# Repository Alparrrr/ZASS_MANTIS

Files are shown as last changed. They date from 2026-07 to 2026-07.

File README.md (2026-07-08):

# ZASS MANTIS — Battery Display & Logger Unit

STM32-based display and control unit designed for **ZASS Lithium Battery Packs**.

The system reads battery telemetry over **FDCAN / RS485**, visualizes it on a **DWIN HMI** touch screen via UART, and logs every frame received from the pack to an SD card.

<p align="center">
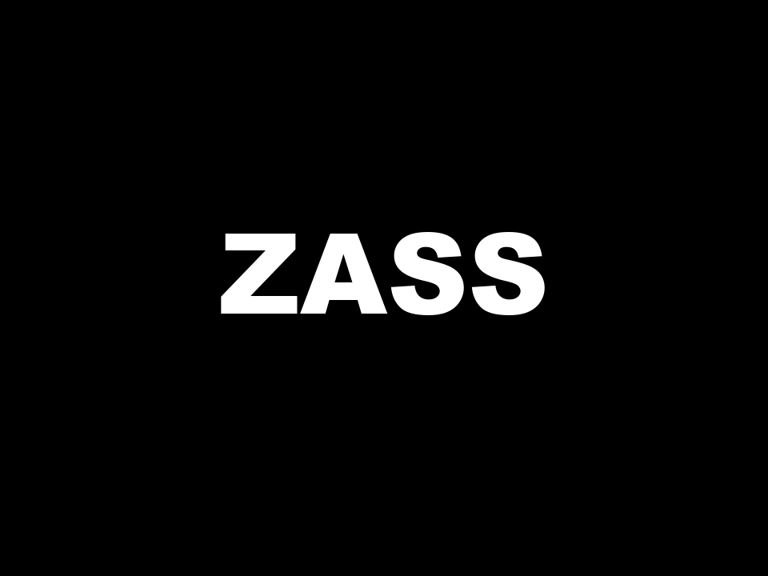
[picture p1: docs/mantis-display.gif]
ZASS MANTIS display — boot screen and live telemetry dashboard
  
  <br/>
  <em>Boot sequence and live telemetry dashboard (DWIN HMI, 320×240)</em>
</p>

## Features

- 📊 Displays cell voltages, total pack voltage, SOC and temperature
- 🔌 **2× FDCAN** and **1× RS485** communication ports
- 🖥️ **UART** driver for the DWIN HMI display
- ⚠️ Detailed fault monitoring (over-voltage, under-voltage, over-temperature, over-current)
- 💾 Full data logging to SD card (FATFS) — every frame coming from the pack is stored

## Communication Flow

```
BMS ──(FDCAN / RS485)──▶ MANTIS ──(UART / FDCAN)──▶ DWIN DISPLAY
        raw battery data        parsed data & screen variables
```

## SD Card Data Logging

Every frame received from the pack is appended to a daily CSV file. Logs are organized into year / month folders on the SD card:

```
/2026/07_2026/09_07_2026_LOG.CSV
```

Example log content:

```csv
2026.07.09 14:32:01,52.61,3287,3290,3288,3286,3291,3289,3287,3285,26,25,-14.6,78
2026.07.09 14:32:02,52.60,3287,3289,3288,3286,3290,3289,3286,3285,26,25,-14.8,78
2026.07.09 14:32:03,52.58,3286,3289,3287,3285,3290,3288,3286,3284,26,25,-15.1,78
2026.07.09 14:32:04,52.59,3287,3290,3288,3286,3290,3289,3287,3285,26,25,-14.9,78
```

| Column | Field | Unit |
|---|---|---|
| 1 | Timestamp (RTC) | `YYYY.MM.DD hh:mm:ss` |
| 2 | Total pack voltage | V |
| 3–10 | Cell voltages 1–8 | mV |
| 11 | MOSFET temperature | °C |
| 12 | Battery temperature | °C |
| 13 | Current (+ charge / − discharge) | A |
| 14 | State of charge | % |

## Repository Structure

| Folder | Contents |
|---|---|
| `01_HARDWARE_ALTIUM/` | Altium Designer project, Gerber outputs, BOM, 3D STEP model |
| `02_Firmware_STM32/` | STM32CubeIDE firmware project (`ZASS_MANTIS_114`) |
| `04_DWIN_DISPLAY/` | DWIN HMI screen project and image assets |

## Hardware

- **MCU:** STM32 (2× FDCAN)
- **Display:** DWIN HMI (UART)
- **Storage:** microSD card (FATFS)

## Status

| Milestone | State |
|---|---|
| Hardware design | ✅ Completed |
| First sample PCB | ✅ Ordered & validated |
| **-30 version design** | ✅ **Completed** |
| **Production batch (50 units)** | 🏭 **Ordered** |

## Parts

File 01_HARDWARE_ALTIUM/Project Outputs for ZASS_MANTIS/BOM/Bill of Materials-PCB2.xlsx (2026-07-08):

Comment | Description | Designator | Footprint | LibRef | Quantity
CR2032 | BATTERY LITHIUM 3V COIN 20MM | BT1 | FP-CR2032-MFG | CMP-05417-000003-1 | 1
3034TR | BATTERY RETAINER COIN 20MM SMD | BT2 | FP-3034TR-MFG | CMP-19636-000007-1 | 1
CC0805KRX7R5BB104 | CAP CER X7R 0805 | C1, C2, C5, C8, C11, C12, C14, C15 | FP-CC0805-EA-MFG | CMP-03422-000810-2 | 8
C0805C104K5RACTU | CAP CER 0.1UF 50V X7R 0805 | C3, C4, C7, C13 | FP-C0805C-DN-MFG | CMP-2007-00279-2 | 4
06035A220KAT2A |  | C6, C9 | CAPC1608X90X35ML15T15 | CMP-2006-04272-1 | 2
C0805C519D3HACTU | C0805 5.1 pF X8R 30ppm/°C 0.5 pF 25 V | C10, C16 | FP-C0805C-DN-MFG | CMP-03020-033346-1 | 2
LTST-C230EKT | LED RED CLEAR CHIP SMD | D1 | FP-LTST-C230EKT-MFG | CMP-22017-000030-1 | 1
ESDCAN06-2BWY | TVS Diode (Bi-directional) | D2, D4 | SOT65P210X110-3N | ESDCAN06-2BWY | 2
BAT54S-7-F | DIODE ARRAY SCHOTTKY 30V SOT23-3 | D3, D6 | FP-SOT23-MFG | CMP-1667-00006-2 | 2
1N4007WS | Diode | D5 | SOD2613X110N | 1N4007WS | 1
STM32G0B1CBT6TR | Integrated Circuit | IC1 | QFP50P900X900X160-48N | STM32G0B1CBT6TR | 1
TCAN3414DR | Integrated Circuit | IC2, IC3, IC5 | SOIC127P600X175-8N | TCAN3414DR | 3
B2B-XH-A(LF)(SN) | CONN HEADER VERT 2POS 2.5MM | J1 | FP-B2B-XH-A_LF_SN-MFG | CMP-2000-05888-3 | 1
B5B-XH-AM(LF)(SN) | CONN HEADER VERT 5POS 2.5MM | J2 | FP-B5B-XH-AM_LF_SN-MFG | CMP-17439-000304-1 | 1
B3B-XH-A(LF)(SN) | CONN HEADER VERT 3POS 2.5MM | J4, J8, J9, J10 | FP-B3B-XH-A_LF_SN-MFG | CMP-17439-000014-3 | 4
S2B-XH-A(LF)(SN) | CONN HEADER VERT 2POS 2.5MM | J5 | FP-B2B-XH-A_LF_SN-MFG | CMP-2000-05888-3 | 1
B6B-XH-AM(LF)(SN) | CONN HEADER VERT 6POS 2.5MM | J6 | FP-B6B-XH-AM_LF_SN-MFG | CMP-17439-000167-1 | 1
MSD-4-A | Connector | J7 | MSD4A | MSD-4-A | 1
B4B-XH-A(LF)(SN) | CONN HEADER VERT 4POS 2.5MM | P1 | FP-B4B-XH-A_LF_SN-MFG | CMP-17439-000250-1 | 1
AO3422 | MOSFET (N-Channel) | Q1 | SOT95P237X112-3N | AO3422 | 1
SI7113ADN-T1-GE3 | MOSFET P-CH 100V 10.8A 1212-8 | Q2 | FP-S16-2667-SINGLE-MFG | CMP-02550-000064-1 | 1
CRGCQ0603J10K | CRGCQ 0603 10K 5% | R1, R3, R4, R5, R11, R12, R13, R15 | FP-CRGCQ0603-IPC_C | CMP-03211-009884-1 | 8
CRGCQ0603F120R | CRGCQ0603 120Ω 1% ±100ppm/°C 75V | R2, R27, R28 | FP-CRGCQ0603-IPC_C | CMP-03211-001601-1 | 3
CRGCQ1206F1K0 | CRGCQ1206 1KΩ 0.25W 1% ±100ppm/°C 200V | R10 | FP-CRGCQ1206-IPC_C | CMP-03211-006592-1 | 1
CRGCQ0603F1K2 | CRGCQ 0603 1K2 1% | R16, R17, R19 | FP-CRGCQ0603-IPC_C | CMP-03211-000516-1 | 3
RC3216J202CS | 25% 0.25W ±100ppm/°C Molded SMD T/R | R18 | FP-RC3216-IPC_A | CMP-13261-004107-1 | 1
PTS647SK38SMTR2LFS | TACT 4.5 X 4.5, 3.8 MM H, 2.5N, | SW1 | FP-PTS647SK38SMTR2LFS-MFG | CMP-10040-000033-1 | 1
MC7805CDTRKG | IC REG LINEAR 5V 1A DPAK | U1 | FP-369C-MFG | CMP-07128-000033-1 | 1
LM317LD13TR | IC REG LINEAR POS ADJ 100MA 8SO | U2 | FP-SO-8-0016023-MFG | CMP-0244-00272-2 | 1
ECX-.327-CDX-1293 | CRYSTAL 32.7680KHZ 12.5PF SMD | Y1 | FP-ECS-CDX-MFG | CMP-40224-000016-1 | 1
ECS-240-6-37B-7KM-TR | Crystal or Oscillator | Y2 | ECS240637B7KMTR | ECS-240-6-37B-7KM-TR | 1

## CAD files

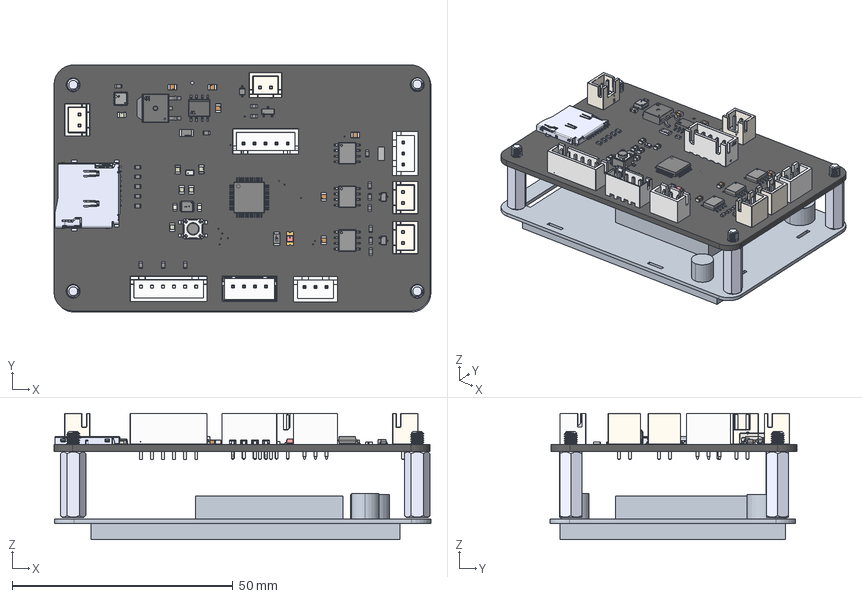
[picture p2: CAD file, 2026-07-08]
01_HARDWARE_ALTIUM/PCB2.step
85.3 x 55.9 x 28.6 mm
Vishay logo - Copy x 5
Vishay logo x 6
terminals x 14
top x 15
value x 14
FilletPinL
FilletPinR x 4
PinsArrayL x 3
Extruded x 7
B2B-XH-A x 4
JST Logo adjustable x 4
JST x 3
Notch
Pins x 2
Marking x 3
JST Logo x 2
Pin1_Triangle x 2
Termination x 3
Logo x 3
LID
IC_BODY
circle
IC_LEG x 4
STMicroelectronics
IC_LEG_MIR5 x 4
ON Semi Logo
ON Semiconductor
Package
Top x 2
Sides
Core
Text Logo
pins
part number
Vishay logo 1
PinsArrayLR x 3
Lite-On Logo Adjustable
Cap_Yageo_CC0805KRX7R5BB104_eec x 24
Cap_KEMET_C0805C472J3HAC_eec x 18
F31132-01 M3x15 Male Female Standoff x 4

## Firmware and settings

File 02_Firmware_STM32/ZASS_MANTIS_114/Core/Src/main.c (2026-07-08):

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
/* Includes ------------------------------------------------------------------*/
#include "main.h"
#include "cmsis_os.h"
#include "app_fatfs.h"

/* USER CODE BEGIN Includes */
#include "stdint.h"
#include "stdbool.h"
#include "string.h"

/* USER CODE END Includes */

/* USER CODE BEGIN PD */
#define BMS_VOLT_MIN 16.0f
#define BMS_VOLT_MAX 30.0f
volatile uint8_t  bms_data_ready;    /* yeni cozulmus veri var */
volatile uint8_t  bms_dump_ready;    /* yeni ham paket var (dump icin) */
volatile uint8_t  bms_data_valid;    /* en az bir GECERLI (sifir-olmayan) paket geldi */
volatile uint32_t bms_last_rx_ms;    /* son gecerli paketin HAL_GetTick() zamani */

/* USER CODE END PD */

RTC_HandleTypeDef hrtc;

SPI_HandleTypeDef hspi1;

UART_HandleTypeDef huart3;
UART_HandleTypeDef huart6;
DMA_HandleTypeDef hdma_usart6_rx;

/* Definitions for defaultTask */
osThreadId_t defaultTaskHandle;
const osThreadAttr_t defaultTask_attributes = {
  .name = "defaultTask",
  .priority = (osPriority_t) osPriorityNormal,
  .stack_size = 256 * 4
};
/* Definitions for myTask02 */
osThreadId_t myTask02Handle;
const osThreadAttr_t myTask02_attributes = {
  .name = "myTask02",
  .priority = (osPriority_t) osPriorityLow,
  .stack_size = 2048 * 4
};
/* USER CODE BEGIN PV */
RTC_DateTypeDef sDate;
RTC_TimeTypeDef sTime;
/* USER CODE END PV */

void SystemClock_Config(void);
static void MX_GPIO_Init(void);
static void MX_DMA_Init(void);
static void MX_SPI1_Init(void);
static void MX_RTC_Init(void);
static void MX_USART3_UART_Init(void);
static void MX_USART6_UART_Init(void);
void StartDefaultTask(void *argument);
void StartTask02(void *argument);

/* USER CODE BEGIN PFP */
// JK BMS "Tüm Verileri Oku" sihirli dizisi

/* USER CODE END PFP */

/* USER CODE BEGIN 0 */
/* USER CODE BEGIN PTD */
// JK BMS'den gelen anlamlı verileri tutacağımız yapı (Struct)
void battery_screen_task(void);

// Durum makinesi (State Machine) adımları
typedef enum {
    WAIT_A5, WAIT_5A, WAIT_5D, WAIT_82, WAIT_10, WAIT_00, RECEIVE_PAYLOAD
} BMS_State;
/* USER CODE END PTD */


/* USER CODE BEGIN PV */
uint16_t BMS = 0;
#define RX_BUF_SIZE 256
uint8_t dma_rx_buf[RX_BUF_SIZE];
#define BMS_PAYLOAD_LENGTH 90
float gercek_akim;
uint16_t CurentCounter ;
uint8_t isFirstStart = 0;
JK_BMS_Data my_bms;              // Her yerden erişebileceğimiz asıl BMS verimiz
BMS_State bms_state = WAIT_A5;   // Başlangıç durumu

uint8_t rx_byte;                 // Anlık okunan 1 byte
uint8_t bms_payload[BMS_PAYLOAD_LENGTH]; // Yakalanan 90 bytelık ana veri
uint16_t payload_index = 0;
volatile uint8_t bms_data_ready = 0;     // Ana döngüye haber verecek bayrak
uint8_t x;
uint8_t dma_raw_buffer[256]; // DMA'nın ham veri karalama defteri
   // Asla kaymayan, jilet gibi sabit dizimiz
volatile uint8_t packet_count = 0; // Kaç tane sağlam paket yakaladık (Debug için)
/* USER CODE END 0 */

/**
  * @brief  The application entry point.
  * @retval int
  */
int main(void)
{

  /* MCU Configuration--------------------------------------------------------*/

  /* Reset of all peripherals, Initializes the Flash interface and the Systick. */
  HAL_Init();

  /* Configure the system clock */
  SystemClock_Config();

  /* Initialize all configured peripherals */
  MX_GPIO_Init();
  MX_DMA_Init();
  MX_SPI1_Init();
  MX_RTC_Init();
  if (MX_FATFS_Init() != APP_OK) {
    Error_Handler();
  }
  MX_USART3_UART_Init();
  MX_USART6_UART_Init();
  /* USER CODE BEGIN 2 */
  // HAL_UART_Receive_IT(&huart6, &rx_byte, 1);
  HAL_GPIO_WritePin(GPIOA, GPIO_PIN_10, RESET);
// UART Idle kesmesini başlat
  HAL_UARTEx_ReceiveToIdle_DMA(&huart6, dma_raw_buffer, 256);
  __HAL_DMA_DISABLE_IT(huart6.hdmarx, DMA_IT_HT);
  /* USER CODE END 2 */

  /* Init scheduler */
  osKernelInitialize();

  /* USER CODE BEGIN RTOS_MUTEX */
  /* add mutexes, ... */
  /* USER CODE END RTOS_MUTEX */

  /* USER CODE BEGIN RTOS_SEMAPHORES */
  /* add semaphores, ... */
  /* USER CODE END RTOS_SEMAPHORES */

  /* USER CODE BEGIN RTOS_TIMERS */
  /* start timers, add new ones, ... */
  /* USER CODE END RTOS_TIMERS */

  /* USER CODE BEGIN RTOS_QUEUES */
  /* add queues, ... */
  /* USER CODE END RTOS_QUEUES */

  /* Create the thread(s) */
  /* creation of defaultTask */
  defaultTaskHandle = osThreadNew(StartDefaultTask, NULL, &defaultTask_attributes);

  /* creation of myTask02 */
  myTask02Handle = osThreadNew(StartTask02, NULL, &myTask02_attributes);

  /* USER CODE BEGIN RTOS_THREADS */
  /* add threads, ... */
  /* USER CODE END RTOS_THREADS */

  /* USER CODE BEGIN RTOS_EVENTS */
  /* add events, ... */
  /* USER CODE END RTOS_EVENTS */

  /* Start scheduler */
  osKernelStart();

  /* We should never get here as control is now taken by the scheduler */

  /* Infinite loop */
  /* USER CODE BEGIN WHILE */
  while (1)
  {
    /* USER CODE END WHILE */

    /* USER CODE BEGIN 3 */
	  // 1. Buffer'ı temizle
	  // Komutu hatta gönder (6 byte)


  }
  /* USER CODE END 3 */
}

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
/* USER CODE BEGIN 4 */
/*void BMS_Mesajini_Coz(void) {
    my_bms.battery_volts   = (float)((bms_payload[0] << 8) | bms_payload[1]) / 100.0;
    my_bms.battery_current = (int16_t)((bms_payload[2] << 8) | bms_payload[3]);
    my_bms.soc             = (bms_payload[6] << 8) | bms_payload[7];
    my_bms.cell_delta      = (bms_payload[8] << 8) | bms_payload[9];
    my_bms.mos_temp        = (int16_t)((bms_payload[10] << 8) | bms_payload[11]);
    my_bms.batt_temp       = (int16_t)((bms_payload[12] << 8) | bms_payload[13]);
    my_bms.warning         = (bms_payload[14] << 8) | bms_payload[15];
    my_bms.ave_cell_volt   = (bms_payload[16] << 8) | bms_payload[17];
    my_bms.balance_status  = (bms_payload[18] << 8) | bms_payload[19];
    my_bms.charge_mos      = (bms_payload[20] << 8) | bms_payload[21];
    my_bms.discharge_mos   = (bms_payload[22] << 8) | bms_payload[23];

    // İlk 8 hücrenin voltajını okuma (Kendi hücre sayına göre artırabilirsin)
    for (int i = 0; i < 8; i++) {
        uint16_t cell_index = 24 + (i * 2);
        my_bms.cell_volts[i] = (bms_payload[cell_index] << 8) | bms_payload[cell_index + 1];
    }
}*/
void BMS_Mesajini_Coz(uint16_t header_index) {

    // Asıl veriler (payload) başlıktan 6 byte sonra başlıyor
    // Eski kodundaki 0. index, artık p + 0 anlamına gelecek.
    uint16_t p = header_index + 6;

    my_bms.battery_volts   = (float)((dma_raw_buffer[p + 0] << 8) | dma_raw_buffer[p + 1]) / 100.0f;
    my_bms.battery_current = (int16_t)((dma_raw_buffer[p + 2] << 8) | dma_raw_buffer[p + 3]);
    my_bms.soc             = (dma_raw_buffer[p + 6] << 8) | dma_raw_buffer[p + 7];
    my_bms.cell_delta      = (dma_raw_buffer[p + 8] << 8) | dma_raw_buffer[p + 9];
    my_bms.mos_temp        = (int16_t)((dma_raw_buffer[p + 10] << 8) | dma_raw_buffer[p + 11]);
    my_bms.batt_temp       = (int16_t)((dma_raw_buffer[p + 12] << 8) | dma_raw_buffer[p + 13]);
    my_bms.warning         = (dma_raw_buffer[p + 14] << 8) | dma_raw_buffer[p + 15];
    my_bms.ave_cell_volt   = (dma_raw_buffer[p + 16] << 8) | dma_raw_buffer[p + 17];
    my_bms.balance_status  = (dma_raw_buffer[p + 18] << 8) | dma_raw_buffer[p + 19];
    my_bms.charge_mos      = (dma_raw_buffer[p + 20] << 8) | dma_raw_buffer[p + 21];
    my_bms.discharge_mos   = (dma_raw_buffer[p + 22] << 8) | dma_raw_buffer[p + 23];

    // İlk 8 hücrenin voltajını okuma
    for (int i = 0; i < 8; i++) {
        uint16_t cell_index = p + 24 + (i * 2);
        my_bms.cell_volts[i] = (dma_raw_buffer[cell_index] << 8) | dma_raw_buffer[cell_index + 1];
    }
}

void HAL_UARTEx_RxEventCallback(UART_HandleTypeDef *huart, uint16_t Size)
{
    if (huart->Instance == USART6)
    {
        for (int i = 0; i <= (Size - 96); i++)
        {
            if (dma_raw_buffer[i] == 0xA5 &&
                dma_raw_buffer[i+1] == 0x5A &&
                dma_raw_buffer[i+2] == 0x5D &&
                dma_raw_buffer[i+3] == 0x82)
            {
                // BİNGO! Başlığı bulduk.
                // Tek yapmamız gereken "i" (başlangıç indexi) değerini fonksiyonumuza göndermek.
                BMS_Mesajini_Coz(i);

                bms_data_ready = 1; // Ana döngüye haber ver
                bms_last_rx_ms = HAL_GetTick();   // <-- SADECE BU SATIRI EKLE (mesaj geldi -> zaman damgası)
                break;
            }
        }


        // Yeniden dinlemeyi kur
        HAL_UART_AbortReceive(huart);
        HAL_UARTEx_ReceiveToIdle_DMA(huart, dma_raw_buffer, 256);
        __HAL_DMA_DISABLE_IT(huart->hdmarx, DMA_IT_HT);
    }
}

// Hata olursa kilitlenmeyi çözen kurtarıcı
void HAL_UART_ErrorCallback(UART_HandleTypeDef *huart)
{
    if (huart->Instance == USART6)
    {
        __HAL_UART_CLEAR_OREFLAG(huart);
        __HAL_UART_CLEAR_NEFLAG(huart);
        __HAL_UART_CLEAR_FEFLAG(huart);

        HAL_UART_AbortReceive(huart);
        HAL_UARTEx_ReceiveToIdle_DMA(huart, dma_raw_buffer, 256);
        __HAL_DMA_DISABLE_IT(huart->hdmarx, DMA_IT_HT);
    }
}
void DWIN_Ekrana_Yaz_RTOS(uint16_t vp_address, uint16_t value) {
    uint8_t dwin_frame[8];
    dwin_frame[0] = 0x5A;
    dwin_frame[1] = 0xA5;
    dwin_frame[2] = 0x05;
    dwin_frame[3] = 0x82;
    dwin_frame[4] = (vp_address >> 8);
    dwin_frame[5] = (vp_address & 0xFF);
    dwin_frame[6] = (value >> 8);
    dwin_frame[7] = (value & 0xFF);

    HAL_UART_Transmit(&huart3, dwin_frame, 8, 100);

    // RTOS'ta bu görev uyurken diğer görevler (SD Kart, CAN) çalışmaya devam eder
    osDelay(5); // CMSIS-RTOS kullanıyorsan osDelay, saf FreeRTOS ise vTaskDelay(pdMS_TO_TICKS(5))
}
void DWIN_Float_Yaz(uint16_t vp_address, float value) {
    uint8_t dwin_frame[10]; // Float için paket daha uzundur (10 byte)

    dwin_frame[0] = 0x5A;
    dwin_frame[1] = 0xA5;
    dwin_frame[2] = 0x07; // Uzunluk: Komut(1) + Adres(2) + Float Veri(4) = 7
    dwin_frame[3] = 0x82; // Yazma Komutu

    dwin_frame[4] = (vp_address >> 8);  // VP Adres High
    dwin_frame[5] = (vp_address & 0xFF);// VP Adres Low

    // Sihirli Kısım: Float değişkenini RAM'de byte byte parçalıyoruz
    uint8_t *float_bytes = (uint8_t *)&value;

    // STM32 (Little-Endian) -> DWIN (Big-Endian) dönüşümü için ters sıralıyoruz
    dwin_frame[6] = float_bytes[3];
    dwin_frame[7] = float_bytes[2];
    dwin_frame[8] = float_bytes[1];
    dwin_frame[9] = float_bytes[0];

    HAL_UART_Transmit(&huart3, dwin_frame, 10, 100);
}
/* Cozulen paket makul mu? (sifir / cop paketleri ele) */
static uint8_t bms_frame_plausible(void)
{
    if (my_bms.battery_volts < BMS_VOLT_MIN) return 0;  /* 0 dahil mantiksiz */
    if (my_bms.battery_volts > BMS_VOLT_MAX) return 0;
    return 1;
}

uint8_t BMS_IsReady(void)
{
    if (!bms_data_ready) return 0;
    return ((HAL_GetTick() - bms_last_rx_ms) <= 3000) ? 1 : 0;
}

void BMS_Buzzer_Update(void)
{
    /* 1) Henuz gecerli veri yok VEYA veri bayatladi -> KESIN SUS */
    if (!BMS_IsReady()) {
        HAL_GPIO_WritePin(GPIOA, GPIO_PIN_10, GPIO_PIN_RESET);
        return;
    }
    /* 2) Gercek alarm varsa ot, yoksa sus */
    if (my_bms.warning != 0 || my_bms.soc <= 20){

        HAL_GPIO_WritePin(GPIOA, GPIO_PIN_10, GPIO_PIN_SET);
        CurentCounter = 0;

        if(my_bms.soc <= 20 && my_bms.battery_current >=1){
        	CurentCounter++;

        			if(CurentCounter >=30){
        				HAL_GPIO_WritePin(GPIOA, GPIO_PIN_10, RESET);
        			}

        	HAL_GPIO_WritePin(GPIOA, GPIO_PIN_10, GPIO_PIN_RESET);
        }
    }
    else
        HAL_GPIO_WritePin(GPIOA, GPIO_PIN_10, GPIO_PIN_RESET);
}

/* USER CODE END 4 */

/* USER CODE BEGIN Header_StartDefaultTask */
/**
  * @brief  Function implementing the defaultTask thread.
  * @param  argument: Not used
  * @retval None
  */
/* USER CODE END Header_StartDefaultTask */
void StartDefaultTask(void *argument)
{
  /* USER CODE BEGIN 5 */
  /* Infinite loop */
  for(;;)
  {

	  x++;
	  HAL_GPIO_TogglePin(GPIOB, GPIO_PIN_12);
	  // 1. ADIM: 36 Byte'lık paketi UART6 üzerinden gönder
	  //
	 /* // Eğer kesme fonksiyonu tam bir 0x1000 paketini başarıyla aldıysa:
	  if (bms_data_ready == 1) {

	            bms_data_ready = 0; // Bayrağı hemen indir

	            // Ham byte dizisini float ve int değerlerine çevir
	            BMS_Mesajini_Coz();

	            // -> TEBRİKLER! VERİLER HAZIR <-
	            // Debug modunda "my_bms" struct'ını izlemeye al.
	            // my_bms.battery_volts 26.33 vb. değerleri canlı göreceksin.
	        }*/
	  // SoC - 0x1000
	             // DWIN_Ekrana_Yaz_RTOS(0x1000, my_bms.soc);

	              // Voltaj - 0x1060 (26.33V -> 263 gönderiyoruz)
	        //      DWIN_Float_Yaz(0x1060, my_bms.battery_volts);

	              // Akım - 0x1080
	           //   float gercek_akim = (float)my_bms.battery_current / 10.0f ;
	                        // Not: BMS akımı 100 katı veriyorsa burayı 100.0f yapmalısın.
	           //             DWIN_Float_Yaz(0x1080, gercek_akim);

	              // Sıcaklıklar
	           //   DWIN_Ekrana_Yaz_RTOS(0x1020, (uint16_t)my_bms.mos_temp);
	     //         DWIN_Ekrana_Yaz_RTOS(0x1040, (uint16_t)my_bms.batt_temp);
	       //       SOC_Bar_Guncelle(gercek_akim, my_bms.soc);
	  DWIN_Float_Yaz(0x1060, my_bms.battery_volts);          // voltaj (senin)
	      float gercek_akim = (float)my_bms.battery_current / 10.0f;
	      DWIN_Float_Yaz(0x1080, gercek_akim);                   // akim (senin)
	      Akim_Renk_Guncelle(gercek_akim);
	      DWIN_Ekrana_Yaz_RTOS(0x1020, (uint16_t)my_bms.mos_temp);
	      DWIN_Ekrana_Yaz_RTOS(0x1040, (uint16_t)my_bms.batt_temp);
	      Sicaklik_Renk_Guncelle(my_bms.mos_temp, my_bms.batt_temp);
	      Akim_Renk_Guncelle(gercek_akim);
	      if (HAL_GetTick() - bms_last_rx_ms > 3000) {
	               bms_data_ready = 0;
	           }

	      if (BMS_IsReady()) {
	          BMS_Buzzer_Update();
	      }

	      SOC_Bar_Guncelle(my_bms.soc, gercek_akim);             // <-- EKLE: SOC+bar+durum+renk
    osDelay(100);
  }
  /* USER CODE END 5 */
}

/* USER CODE BEGIN Header_StartTask02 */
/**
* @brief Function implementing the myTask02 thread.
* @param argument: Not used
* @retval None
*/
/* USER CODE END Header_StartTask02 */
void StartTask02(void *argument)
{
  /* USER CODE BEGIN StartTask02 */
  /* Infinite loop */
  for(;;)
  {
	SD_Log_Process();
	//  HAL_GPIO_WritePin(GPIOA, GPIO_PIN_12, SET);

    osDelay(1000);
  }
  /* USER CODE END StartTask02 */
}

/**
  * @brief  Period elapsed callback in non blocking mode
  * @note   This function is called  when TIM2 interrupt took place, inside
  * HAL_TIM_IRQHandler(). It makes a direct call to HAL_IncTick() to increment
  * a global variable "uwTick" used as application time base.
  * @param  htim : TIM handle
  * @retval None
  */
void HAL_TIM_PeriodElapsedCallback(TIM_HandleTypeDef *htim)
{
  if (htim->Instance == TIM2)
  {
    HAL_IncTick();
  }
}

/**
  * @brief  This function is executed in case of error occurrence.
  * @retval None
  */
void Error_Handler(void)
{
  /* USER CODE BEGIN Error_Handler_Debug */
  /* User can add his own implementation to report the HAL error return state */
  __disable_irq();
  while (1)
  {
  }
  /* USER CODE END Error_Handler_Debug */
}
#ifdef USE_FULL_ASSERT
/**
  * @brief  Reports the name of the source file and the source line number
  *         where the assert_param error has occurred.
  * @param  file: pointer to the source file name
  * @param  line: assert_param error line source number
  * @retval None
  */
void assert_failed(uint8_t *file, uint32_t line)
{
  /* USER CODE BEGIN 6 */
  /* User can add his own implementation to report the file name and line number,
     ex: printf("Wrong parameters value: file %s on line %d\r\n", file, line) */
  /* USER CODE END 6 */
}
#endif /* USE_FULL_ASSERT */

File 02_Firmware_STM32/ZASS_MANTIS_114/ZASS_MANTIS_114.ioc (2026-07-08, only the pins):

Mcu.UserName=STM32G0B1CBTx
PA10.Signal=GPIO_Output
PA13.Signal=SYS_SWDIO
PA14-BOOT0.Signal=SYS_SWCLK
PA4.GPIO_Label=SPI1_CS
PA4.Signal=GPIO_Output
PA5.Signal=SPI1_SCK
PA6.Signal=SPI1_MISO
PA7.Signal=SPI1_MOSI
PB10.Signal=USART3_TX
PB11.Signal=USART3_RX
PB12.Signal=GPIO_Output
PB8.Signal=USART6_TX
PB9.Signal=USART6_RX

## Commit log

2026-03-10 MANTIS hardware design completed and first sample PCB ordered
    [Bill of Materials-ZASS_MANTIS.xlsx, MAIN.SchDoc, PCB1.PcbDoc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]
2026-07-08 MANTIS -30 version design completed and 50-unit production batch ordered
    - Hardware: schematic and PCB updated for the -30 version, Gerber outputs regenerated, BOM and 3D STEP model added
    - Firmware: project migrated to ZASS_MANTIS_114 (STM32CubeIDE, FATFS SD logging)
    - Display: DWIN HMI screen assets updated
    - Repo: fixed broken wildcard patterns in .gitignore, rewrote README with structure, hardware overview and project status
    [Bill of Materials-PCB2.xlsx, COMM.SchDoc, MAIN.SchDoc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]
2026-07-08 Improve README demo GIF: hi-res redraw with status bar and SOC color states
    - Rendered at 960x720 (3x) for a sharp image instead of upscaled 320x240
    - Added the top-right status indicator (BEKLEMEDE / SARJ OLUYOR / DESARJ OLUYOR) recovered from the 55.icl icon library
    - SOC value and charge bar now change color with charge level (green / orange / red) as on the real device
    - Demo scenario: boot -> standby -> charging -> discharge down to low-battery warning -> recovery
2026-07-08 Match demo GIF to firmware behaviour; document SD card CSV logging
    - GIF colors/state logic now follow soc_bar.c exactly: SOC value and bar
    are amber in standby, green while charging, blue while discharging and
    red at SOC <= 20%; temperature values use the firmware white->blue->red
    color ramp; status chip colors sampled from the 55.icl icon library
    - Current is now signed as on the device: negative while discharging
    - README: added SD card logging section with folder layout, real CSV row
    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
2026-10-12 Firmware 115: safety warnings, dual BMS source, SD/RTC logging; -30 C test passed, +100 units ordered
    Status
    - Cold test at -30 C passed.
    - 100 additional units ordered on top of the 50-unit production batch.
    Hardware
    - PCB1/PCB2: backup battery added, SD card socket moved. Design otherwise
    unchanged. All components automotive grade (AEC-Q100 / AEC-Q102).
    Firmware (02_Firmware_STM32/ZASS_MANTIS_115, replaces ZASS_MANTIS_114)
    - 8 safety rules with on-screen strip or pop-up, buzzer patterns and an
    on-board flash event memory.
    - One decoder for CAN (protocol V2.1, up to 25 cells) and UART; CAN has
    priority, UART takes over when CAN goes quiet.
    - SD logging: per-second CSV with every cel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

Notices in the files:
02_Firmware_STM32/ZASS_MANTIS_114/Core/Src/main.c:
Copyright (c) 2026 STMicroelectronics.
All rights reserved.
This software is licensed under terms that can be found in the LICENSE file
